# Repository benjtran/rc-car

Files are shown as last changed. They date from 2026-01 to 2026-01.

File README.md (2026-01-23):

# Mobile Robot

A 4WD mobile robot buggy running SLAM for real time motion planning.

<figure>
    <figcaption>Figure 1: Isometric View of Robot</figcaption>
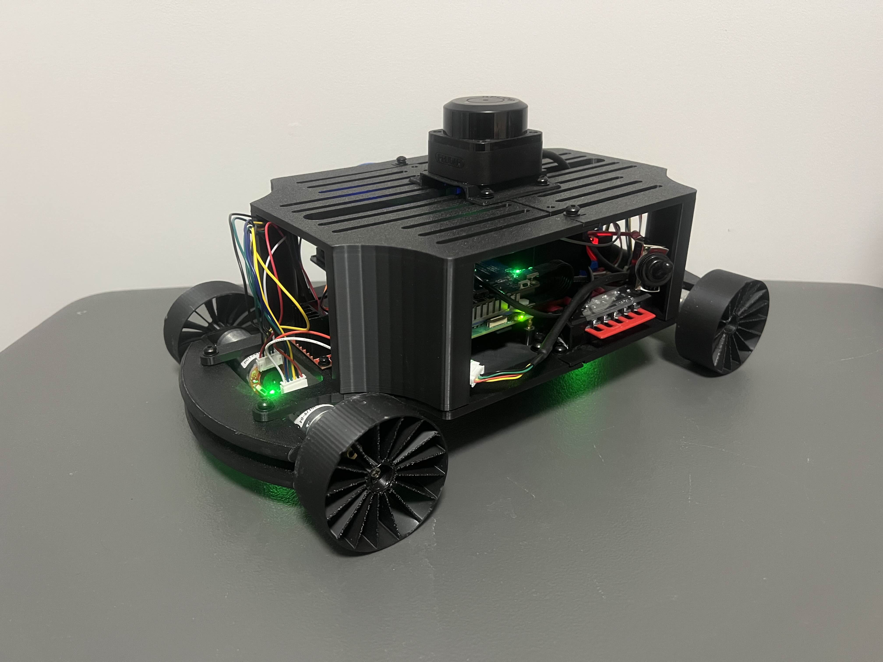
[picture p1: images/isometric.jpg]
    
</figure>

<figure>
    <figcaption>Figure 2: Demo of Robot in Random Environment</figcaption>
    Iris Plot
</figure>

Note: This project was supposed to be an RC car, hence the repo name. I reworked it to see if I could make it autonomous!

## Hardware

### Mechanical:

The chassis and body were custom-designed in Autodesk Inventor. The wheels were sourced from Bambu Studio. All components were 3D printed with PLA.

<figure>
    <figcaption>Figure 3: Isometric View of Chassis and Body</figcaption>
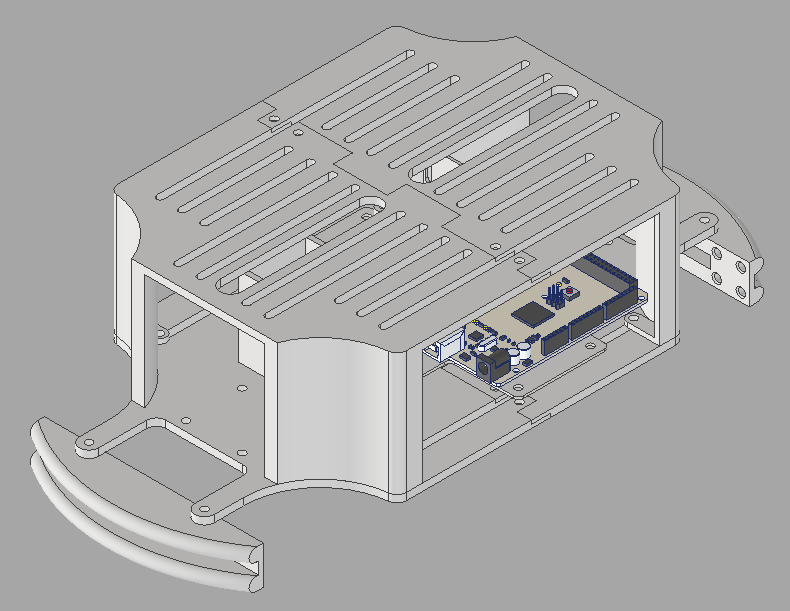
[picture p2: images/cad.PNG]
    
</figure>

### Electrical:
- [1 x Raspberry Pi 5](https://www.amazon.ca/Raspberry-Pi-8GB-2023-Processor/dp/B0CK2FCG1K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)
- [1 x Arduino Mega 2560](https://www.amazon.ca/ELEGOO-Compatible-Arduino-Projects-Compliant/dp/B01H4ZLZLQ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)
- [1 x 12V 5600mAh Lithium Ion Battery](https://www.amazon.ca/Mspalocell-Rechargeable-Battery-Compatible-Electronic/dp/B0D6R4RK26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)
- [1 x GreekPi Power Expansion Board](https://www.amazon.ca/GeeekPi-Expansion-Raspberry-Automatic-Function/dp/B0CYPRDY9Q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)
- [2 x L298N Motor Driver](https://www.amazon.ca/BOJACK-H-Bridge-Controller-Intelligent-Mega2560/dp/B0C5JCF5RS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)
- [4 x 12V DC Geared Motor with Encoder](https://www.amazon.ca/Encoder-Mounting-Bracket-Magnetic-Reduction/dp/B07WT2TCPZ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)
- [1 x RPLIDAR C1](https://www.amazon.ca/SLAMTEC-Navigation-Obstacle-Avoidance-Interface/dp/B0FRM8KHZF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)

## Software

1. Initialization: The Raspberry Pi launches the ROS network.

2. Sensing: The RPLIDAR node publishes raw 2D laser scan data (/scan) of the room.

3. SLAM: The Hector SLAM node listens for /scan to simultaneously build a 2D Occupancy Grid (/map) and estimate the robot's location (/tf).

4. Costmap: Path Planner node converts the map into a Costmap, assigning a cost to each cell of the grid indicating danger levels (cells close to walls are dangerous).

5. Frontier Selection: Path Planner node identifies frontiers (boundaries between free and unknown space), filters out blind spots on lidar, and selects the closest reachable target.

6. Pathfinding: Path Planner node generates a path to the target using A*, prioritizing paths through the center of open spaces rather than hugging dangerous areas.

7. Path Following: Path Planner node uses an incremental controller to drive the robot waypoint-by-waypoint, adjusting velocity and heading to follow the trajectory.

8. Active Safety Check: Path Planner node continuously traces the path ahead; if an obstacle appears or the robot drifts unexpectedly, it halts immediately to replan.

9. Emergency Escape: Path Planner Node checks entering a high-danger zone (too close to a wall), a high-priority "Escape" behavior overrides the planner to back the robot away.

10. Re-planning: Path Planner Node monitors the target frontier; if the target area is completely mapped before arrival, it cancels the current path and selects a new frontier.

11. Velocity Commands: Path Planner Node computes required velocity for each motor and publishes to /cmd_vel.

12. Motor Interface: Motor Interface Node listens for /cmd_vel and sends it to Arduino through serial.

13. Motor Controller: Arduino recieves target velocities and controls motor speeds using a PID controller.

11. Completion: The loop repeats until no accessible frontiers remain, at which point the robot stops.

## Setup Instructions (for me)

1. Run GUI enabled docker container:
```bash
xhost +local:docker
sudo docker start hector_ros
sudo docker exec -it hector_ros bash
```
2. Start ROS1:
```bash
source /opt/ros/noetic/setup.bash
roscore
```
3. Enter second container:
```bash
sudo docker exec -it hector_ros bash
```
4. Launch rplidar:
```bash
source /opt/ros/noetic/setup.bash
cd ~/rc-car/catkin_ws
source devel/setup.bash
roslaunch rplidar_ros view_rplidar_c1.launch
```
5. Enter third container:
```bash
sudo docker exec -it hector_ros bash 
```
6. Launch SLAM:
```bash
source /opt/ros/noetic/setup.bash
cd ~/rc-car/catkin_ws
source devel/setup.bash
roslaunch hector_slam_launch tutorial.launch
```
6. Enter fourth container:
```bash
sudo docker exec -it hector_ros bash 
```
7. Start motor interface:
```bash
source /opt/ros/noetic/setup.bash
cd ~/rc-car/catkin_ws
source devel/setup.bash
rosrun robot_control motor_interface_node.py 
```
8. Enter fifth container:
```bash
sudo docker exec -it hector_ros bash 
```
9. Start path planning:
```bash
source /opt/ros/noetic/setup.bash
cd ~/rc-car/catkin_ws
source devel/setup.bash
rosrun robot_navigation path_planner_node.py 
```

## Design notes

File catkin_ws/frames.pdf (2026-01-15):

view_frames Result

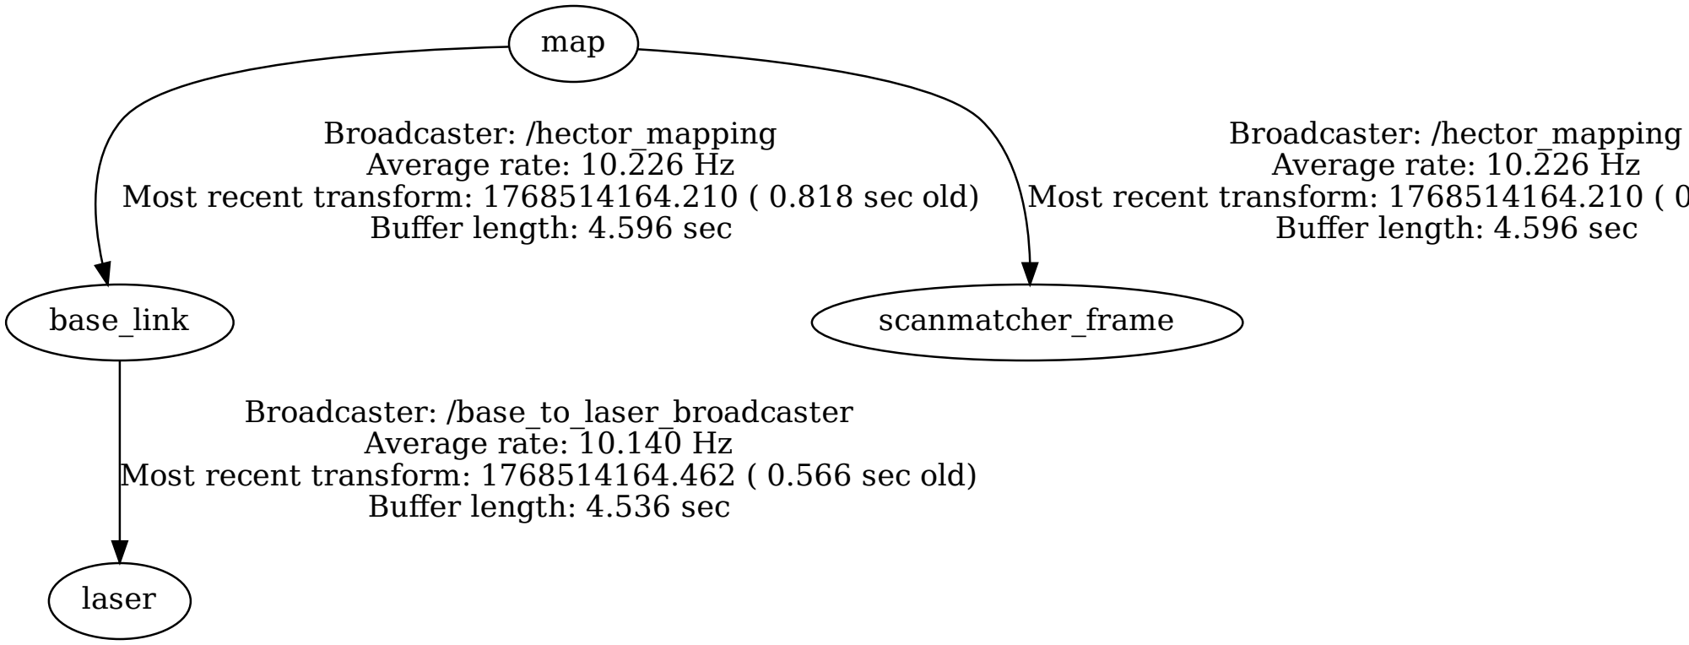
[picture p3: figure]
map; base_link; Broadcaster: /hector_mapping Average rate: 10.226 Hz; Buffer length: 4.596 sec; scanmatcher_frame; laser; Broadcaster: /base_to_laser_broadcaster Average rate: 10.140 Hz; Buffer length: 4.536 sec

Most recent transform: 1768514164.210 ( 0.818 sec old)

Most recent transform: 1768514164.210 ( 0.818 sec old)

Most recent transform: 1768514164.462 ( 0.566 sec old)

Recorded at time: 1768514165.027

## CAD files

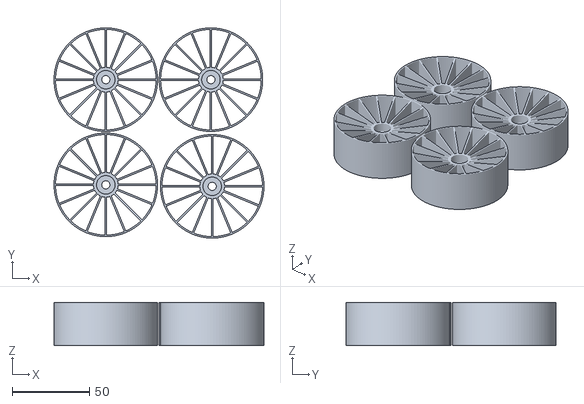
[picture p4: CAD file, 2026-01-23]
parts/1 10 RC AIRLESS TIRES V5.stl
135.8 x 136.0 x 28.0

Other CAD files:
parts/RC_CAR_ARDUINO_PLATE.ipt
parts/RC_CAR_BASE_PLATE.ipt
parts/RC_CAR_BUMPER.ipt
parts/RC_CAR_CHASSIS.iam
parts/RC_CAR_CONTROLLER_PLATE.ipt
parts/RC_CAR_LIDAR_PLATE.ipt
parts/RC_CAR_TOP_PLATE.ipt

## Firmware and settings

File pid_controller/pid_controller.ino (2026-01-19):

/*

4 wheel drive PID control
- Recieves velocity commands from motor interface node via serial
- Translates velocity -> encoder counts
- Controls motors using PID drive

  MOTOR LAYOUT:
  1 0-------0 2
       pi
     battery
  3 0-------0 4

*/

#include <util/atomic.h>

#define NUMMOTORS 4
const int in1[] = {22, 26, 30, 34};
const int in2[] = {24, 28, 32, 36};
const int en[] = {6, 5, 7, 8};
const int enca[] = {18, 21, 3, 2};
const int encb[] = {43, 51, 42, 48};

// globals
long prev_t = 0;
volatile long pos[] = {0, 0, 0, 0};
long prev_pos[] = {0, 0, 0, 0};

// target velocities in m/s
float target_vel[] = {0.0, 0.0, 0.0, 0.0};

// Function declarations
template <int j>
void readEncoder();
void setMotor(int dir, int pwm_val, int en, int ina, int inb);

class Controller {
  private:
    float kp, kd, ki, umax;
    float e_prev, e_integral;
  public:
    Controller() : kp(1), kd(0), ki(0), umax(255), e_prev(0.0), e_integral(0.0){}

  void setParams(float kp_new, float kd_new, float ki_new, float umax_new) {
    kp = kp_new;
    kd = kd_new;
    ki = ki_new;
    umax = umax_new;
  }

  void getSignal(float actual_vel, float target_vel, float dt, int &pwr, int &dir) {
    // error in velocity
    float e = target_vel - actual_vel;

    // derivative
    float dedt = (e - e_prev) / dt;

    // integral
    e_integral = e_integral + e * dt;

    // control signal
    float u = kp * e + kd * dedt + ki * e_integral;

    // motor power
    pwr = (int) fabs(u);
    if (pwr > umax) {
      pwr = umax;
    }

    // motor direction
    dir = 1;
    if (u < 0) {
      dir = -1;
    }

    e_prev = e;
  }
};

Controller controller[NUMMOTORS];

void setup() {
  Serial.begin(9600);
  delay(3000);
  Serial.println("BOOT OKAY");
  for (int i = 0; i < NUMMOTORS; i++) {
    pinMode(in1[i], OUTPUT);
    pinMode(in2[i], OUTPUT);
    pinMode(en[i], OUTPUT);
    pinMode(enca[i], INPUT);
    pinMode(encb[i], INPUT);
  }

  // velocity control
  controller[0].setParams(100, 5, 10, 255);
  controller[1].setParams(100, 5, 10, 255);
  controller[2].setParams(100, 5, 10, 255);
  controller[3].setParams(100, 5, 10, 255);

  attachInterrupt(digitalPinToInterrupt(enca[0]), readEncoder<0>, RISING);
  attachInterrupt(digitalPinToInterrupt(enca[1]), readEncoder<1>, RISING);
  attachInterrupt(digitalPinToInterrupt(enca[2]), readEncoder<2>, RISING);
  attachInterrupt(digitalPinToInterrupt(enca[3]), readEncoder<3>, RISING);
}

float vel[NUMMOTORS] = {0, 0, 0, 0};

void loop() {
  if (Serial.available() > 0) {
    String command = Serial.readStringUntil('\n');
    command.trim();
  
    int idx = 0;
    char buf[50];
    command.toCharArray(buf, sizeof(buf));
  
    char *token = strtok(buf, ",");
    while (token != NULL && idx < 4) {
      vel[idx] = atof(token);
      target_vel[idx] = vel[idx];
      idx++;
      token = strtok(NULL, ",");
    }
  
    if (idx == 4) {
      Serial.print("Received velocities: ");
      for (int i = 0; i < 4; i++) {
        Serial.print(vel[i], 4);
        Serial.print(" ");
      }
      Serial.println();
    }
  }

  long curr_t = micros();
  float dt = ((float) (curr_t - prev_t)) / (1.0e6);
  
  // Only update at fixed intervals (e.g., 20ms = 50Hz)
  if (dt >= 0.02) {
    prev_t = curr_t;
    
    // Calculate actual velocities from encoder changes
    float pulses_per_turn = 508;
    float pulses_per_meter = pulses_per_turn * 4.75089382365;
    
    int posi[NUMMOTORS];
    ATOMIC_BLOCK(ATOMIC_RESTORESTATE) {
      for (int i = 0; i < NUMMOTORS; i++) {
        posi[i] = pos[i];
      }
    }
    
    float actual_vel[NUMMOTORS];
    for (int i = 0; i < NUMMOTORS; i++) {
      long delta_pos = posi[i] - prev_pos[i];
      actual_vel[i] = (delta_pos / pulses_per_meter) / dt;
      prev_pos[i] = posi[i];
    }

    // Control based on velocity
    for (int i = 0; i < NUMMOTORS; i++) {
      int pwr, dir;
      controller[i].getSignal(actual_vel[i], target_vel[i], dt, pwr, dir);
      setMotor(dir, pwr, en[i], in1[i], in2[i]);
    }

    // Debug output
    Serial.print("Vel: ");
    for (int i = 0; i < NUMMOTORS; i++) {
      Serial.print(actual_vel[i], 3);
      Serial.print(" ");
    }
    Serial.print(" Target: ");
    Serial.print(target_vel[0], 3);
    Serial.println();
  }
} 

void setMotor(int dir, int pwm_val, int en, int ina, int inb) {
  analogWrite(en, pwm_val);
  if (dir == 1) {
    digitalWrite(ina, HIGH);
    digitalWrite(inb, LOW);
  } else if (dir == -1) {
    digitalWrite(ina, LOW);
    digitalWrite(inb, HIGH);
  } else {
    digitalWrite(ina, LOW);
    digitalWrite(inb, LOW);
  }
}

template <int j>
void readEncoder() {
  int b = digitalRead(encb[j]);
  if (b > 0) {
    pos[j]++;
  } else {
    pos[j]--;
  }
}

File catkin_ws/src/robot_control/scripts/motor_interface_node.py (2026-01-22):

#!/usr/bin/env python3
import rospy
import serial
from std_msgs.msg import Float32MultiArray

PORT = '/dev/ttyACM0'
BAUD_RATE = 9600

ser = None 
last_cmd_time = None
WATCHDOG_TIMEOUT = 1.0  # Stop motors if no command for 1 second

def callback(msg):
    global ser, last_cmd_time
    
    if ser is None or not ser.is_open:
        rospy.logwarn_throttle(5, "Serial port not available")
        return
    
    if len(msg.data) != 4:
        rospy.logwarn("Expected 4 wheel velocities, got %d", len(msg.data))
        return
    
    last_cmd_time = rospy.Time.now()

    clamped = [max(-0.3, min(0.3, v)) for v in msg.data]
    
    # Format: v1,v2,v3,v4\n
    cmd = "{:.3f},{:.3f},{:.3f},{:.3f}".format(*clamped)
    
    try:
        ser.write((cmd + "\n").encode())
        rospy.loginfo_throttle(1, "Sent: %s", cmd)
    except serial.SerialException as e:
        rospy.logerr("Serial write error: %s", e)
        # Try to reconnect
        try:
            ser.close()
            ser.open()
            rospy.logwarn("Serial reconnected")
        except:
            pass

def watchdog_timer(event):
    global ser, last_cmd_time
    
    if last_cmd_time is None:
        return
    
    if ser is None or not ser.is_open:
        return
    
    time_since_last = (rospy.Time.now() - last_cmd_time).to_sec()
    
    if time_since_last > WATCHDOG_TIMEOUT:
        rospy.logwarn_throttle(5, "Watchdog: No commands for %.1fs, stopping motors", time_since_last)
        try:
            stop_cmd = "0.000,0.000,0.000,0.000\n"
            ser.write(stop_cmd.encode())
        except serial.SerialException as e:
            rospy.logerr("Watchdog serial error: %s", e)

def main():
    global ser, last_cmd_time
    
    rospy.init_node('motor_interface', anonymous=True)
    rospy.loginfo("Motor interface node started!")
    
    try:
        ser = serial.Serial(PORT, BAUD_RATE, timeout=1)
        rospy.sleep(2.5)  # Allow Arduino to reset (2-3 seconds recommended)
        rospy.loginfo("Serial port opened: %s at %d baud", PORT, BAUD_RATE)
        
        ser.write("0.000,0.000,0.000,0.000\n".encode())
        rospy.loginfo("Sent initial stop command")
        
    except serial.SerialException as e:
        rospy.logerr("Failed to open serial port %s: %s", PORT, e)
        return
    
    rospy.Subscriber('/vel_cmd', Float32MultiArray, callback, queue_size=1)
    
    # Watchdog timer: stops motors if no command received
    rospy.Timer(rospy.Duration(0.5), watchdog_timer)
    
    rospy.loginfo("Listening for velocity commands on /vel_cmd...")
    
    try:
        rospy.spin()
    except rospy.ROSInterruptException:
        pass
    finally:
        if ser is not None and ser.is_open:
            rospy.loginfo("Shutting down - stopping motors")
            try:
                ser.write("0.000,0.000,0.000,0.000\n".encode())
                rospy.sleep(0.1)
            except:
                pass
            ser.close()
            rospy.loginfo("Serial port closed")

if __name__ == "__main__":
    main()

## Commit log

2025-10-26 Add front motor test
2026-01-07 Add tuned PID controller for motor 4
2026-01-07 Adapt controller to multiple motors
2026-01-09 Tune PID params
2026-01-16 Retune PID params
2026-01-16 Add send velocity commands from motor interface node to arduino
2026-01-16 Enable serial read commands on arduino
2026-01-16 Enable publishing from path planner to motor interface
2026-01-16 Bug fix for publishing from path planner
    [motor_interface_node.py, pid_controller.ino]
2026-01-17 Interpret yaw
2026-01-18 Add individual motor control
2026-01-19 Switch to velocity PID control over encoder count
